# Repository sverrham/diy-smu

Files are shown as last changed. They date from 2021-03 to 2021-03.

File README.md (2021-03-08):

# diy-smu
DIY Source Measurement Unit, four quadrant powersupply and ?.? digit volt/current meter.

This is based on http://www.djerickson.com/diy_smu/index.html but with some changes.

- I plan to use the raspberry pi for control, maybe design a front pannel solution using the compute module.

- I want to miniturize it a bit, change 0805 to 0603 as that is also quite easy to solder by hand.

- I do not have to much experience with the analog part but will let this be project to learn from.

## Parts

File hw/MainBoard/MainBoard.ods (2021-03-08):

Component | Description | Part | References | Value | Footprint | Quantity Per PCB | Datasheet | Manufacturer | partnr | manufacturer
1 | Unpolarized capacitor, small symbol | C_Small | C32 C33 C34 | 15p | C_0603 | 3 | ~ | Samsung Electro-Mechanics | CL10C150JB8NNNC
2 | Unpolarized capacitor, small symbol | C_Small | C43 | 100p | C_0603 | 1 | ~ | Samsung Electro-Mechanics | CL10C101JB8NNNC
3 | Polarized capacitor, small US symbol | CP1_Small | C52 | 150p | C_0603 | 1 | ~ | Samsung Electro-Mechanics | CL10C151JB8NFNC
4 | Unpolarized capacitor, small symbol | C_Small | C44 C45 C46 | 270p | C_0603 | 3 | ~ | Samsung Electro-Mechanics | CL10C271JB8NNNC
5 | Unpolarized capacitor, small symbol | C_Small | C35 | 1000p | C_0603 | 1 | ~ | Samsung Electro-Mechanics | CL10B102KB8NNNC
6 | Polarized capacitor, small US symbol | CP1_Small | C40 C41 C42 C54 C55 | 1000p | C_0603 | 5 | ~ | Samsung Electro-Mechanics | CL10B102KB8NNNC
7 | Unpolarized capacitor, small symbol | C_Small | C10 C11 C12 C13 C14 C15 C16 C17 C19 C21 C22 C23 C24 C25 C26 C27 C28 C29 C30 C31 C39 C47 C51 C53 C56 C58 | .1u | C_0603 | 26 | ~ | Samsung Electro-Mechanics | CL10B104KB8NNNL
8 | Polarized capacitor, small US symbol | CP1_Small | C5 C38 | .1u | C_0603 | 2 | ~ | Samsung Electro-Mechanics | CL10B104KB8NNNL
9 | Unpolarized capacitor, small symbol | C_Small | C4 | .01u 500V | C_0805 | 1 | ~ | WÃ¼rth Elektronik | 885342207014
10 | Unpolarized capacitor, small symbol | C_Small | C37 | 150p 500V | C_0805 | 1 | ~ | Yageo | CC0805JRNPOBBN151
11 | Polarized capacitor, small US symbol | CP1_Small | C50 | 22p 100V | C_0603 | 1 | ~ | KEMET | C0603C220J1GACTU
12 | Unpolarized capacitor, small symbol | C_Small | C36 | 22p 500V DNI | C_0805 | 1 | ~
13 | Polarized capacitor, small US symbol | CP1_Small | C48 C49 | 270p HIV COG 500V | C_0805 | 2 | ~ | KEMET | C0805C271JCGAC7800
14 | Unpolarized capacitor, small symbol | C_Small | C2 C3 C8 C9 C18 C20 C57 | 4.7u 25V | C_0603 | 7 | ~ | Taiyo Yuden | TMK107BBJ475KA-T
15 | Polarized capacitor, small US symbol | CP1_Small | C1 C6 C7 | 47uf 25V | CP_Elec_6.3x7.7 | 3 | ~ | Panasonic | EEE-1EA470WP | Panasonic
16 | DUAL SURFACE MOUNT LOW LEAKAGE DIODE, common cathode, SOT-23 | BAV170 | D6 | BAV170 | SOT-23 | 1 | https://no.mouser.com/datasheet/2/115/ds30234-820460.pdf | Diodes Incorporated | BAV170Q-7-F
17 | DUAL SURFACE MOUNT LOW LEAKAGE DIODE, SOT-23 | BAV199 | D2 D3 D4 D5 | BAV199 | SOT-23 | 4 | https://www.diodes.com/assets/Datasheets/ds30232.pdf | Nexperia | BAV199.215
18 | High-speed switching diodes, dual series, SOT-363 | BAV99S | D1 | BAV99S | SOT-23 | 1 | https://assets.nexperia.com/documents/data-sheet/BAV99_SER.pdf | ON | BAV99LT1
19 | Generic connector, single row, 01x03, script generated (kicad-library-utils/schlib/autogen/connector/) | Conn_01x03_Female | J2 | Conn_01x03_Female | PhoenixContact_MC-G_03x3.81mm_Angled | 1 | ~ | On Shore Technology | OSTOQ033251
20 | Generic connector, single row, 01x06, script generated (kicad-library-utils/schlib/autogen/connector/) | Conn_01x06_Female | J3 | Conn_01x06_Female | PhoenixContact_MC-G_06x3.81mm_Angled | 1 | ~ | On Shore Technology | OSTOQ063251
21 | Generic connector, single row, 01x06, script generated (kicad-library-utils/schlib/autogen/connector/) | Conn_01x06_Female | J4 | Conn_01x06_Female | Molex_KK-6410-06_06x2.54mm_Straight | 1 | ~ | Molex KK | WM2704-NDâ€Ž
22 | Generic connector, single row, 01x14, script generated (kicad-library-utils/schlib/autogen/connector/) | Conn_01x14 | J1 | Conn_01x14 | Multicomp_MC9A12-1434_2x07x2.54mm_Straight | 1 | ~ | On Shore Technology | 302-S141
23 | General purpose signal relay, Kemet EC2 Series, DPDT (2 Form C), non-latching, through hole, 60W/125VA, 220VDC/250VAC, 2A, 5V DC coil | EC2-5NU | K1 K2 | EC2-5NU | Kemet-EC2-5NU-0 | 2 | https://content.kemet.com/datasheets/KEM_R7002_EC2_EE2.pdf | KEMET | EC2-5NU
24 | 100uH CM Choke | DR331-105BE | L1 | DR331-105BE | dr331 | 1 | https://www.bourns.com/pdfs/DR331.pdf | Bourns Inc. | DR331-105BE | Bourns Inc.
25 | 0.2A Ic, 40V Vce, Small Signal NPN Transistor, SOT-23 | MMBT3904 | Q1 Q2 | MMBT3904 | SOT-23 | 2 | https://www.onsemi.com/pub/Collateral/2N3903-D.PDF |  | MMBT3904
26 | Resistor, small US symbol | R_Small_US | R75 R76 R77 R78 R79 R80 R81 R82 R83 R84 R85 R86 | 0 | R_0603 | 12 | ~ | Yageo | AC0603JR-070RL
27 | Resistor, small US symbol | R_Small_US | R14 R45 | 1K | R_0603 | 2 | ~ | Yageo | RT0603FRE071KL
28 | Resistor, small US symbol | R_Small_US | R71 R72 R73 R74 | 1.5K | R_0603 | 4 | ~ | Yageo | RC0603FR-071K5L
29 | Resistor, small US symbol | R_Small_US | R31 R32 R33 R50 R58 | 2K | R_0603 | 5 | ~ | Yageo | RC0603FR-072KL
30 | Resistor, small US symbol | R_Small_US | R11 R17 R51 R54 | 4.99K | R_0603 | 4 | ~ | Yageo | RC0603FR-074K99L
31 | Resistor, small US symbol | R_Small_US | R12 R13 R16 R43 R44 R53 R63 R64 | 10K | R_0603 | 8 | ~ | Yageo | RT0603FRE0710KL
32 | Resistor, small US symbol | R_Small_US | R18 | 15K | R_0603 | 1 | ~ | Yageo | RC0603FR-0715KL
33 | Resistor, small US symbol | R_Small_US | R8 R9 | 20K | R_0603 | 2 | ~ | Yageo | RC0603FR-0720KL
34 | Resistor, small US symbol | R_Small_US | R1 | 100K | R_0603 | 1 | ~ | Yageo | RC0603JR-07100KL
35 | Resistor, small US symbol | R_Small_US | R39 R40 | 100 1W | R_2512 | 2 | ~ | Yageo | RC2512JK-07100RL
36 | Resistor, small US symbol | R_Small_US | R46 R47 R48 R49 | 100K .1% | R_0603 | 4 | ~ | Yageo | RT0603BRD07100KL
37 | Resistor, small US symbol | R_Small_US | R2 R3 R4 R5 R6 R7 R19 R20 R21 R22 R23 R24 R25 R26 R55 R59 R60 R61 R62 R65 R67 R69 R70 | 10K .1% | R_0603 | 23 | ~ | Yageo | RT0603BRD1010KL
38 | Resistor, small US symbol | R_Small_US | R52 | 10K 1206 | R_1206 | 1 | ~ | Yageo | AC1206FR-0710KL
39 | Resistor, small US symbol | R_Small_US | R41 R42 | 2 1W | R_2512 | 2 | ~ | Yageo | RC2512JK-072RL
40 | Resistor, small US symbol | R_Small_US | R29 | 20.5K .1% | R_0603 | 1 | ~ | Yageo | RT0603BRD0720K5L
41 | Resistor, small US symbol | R_Small_US | R15 | 200K 1206 | C_0805 | 1 | ~ | Yageo | RC0805FR-07200KL
42 | Resistor, small US symbol | R_Small_US | R10 | 20K .1% | R_0603 | 1 | ~ | Yageo | RT0603BRD0720KL
43 | Resistor, small US symbol | R_Small_US | R27 R30 R66 R68 | 21.5K .1% | R_0603 | 4 | ~ | Yageo | RT0603BRD0721K5L
44 | Resistor, small US symbol | R_Small_US | R57 | 22.1K .1% | R_0603 | 1 | ~ | Yageo | RT0603BRD0722K1L
45 | Resistor, small US symbol | R_Small_US | R28 | 2K .1% | R_0603 | 1 | ~ | Yageo | RT0603BRE072KL
46 | Resistor, small US symbol | R_Small_US | R56 | 300K .1% 1206 | R_1206 | 1 | ~ | Susumu | RG3216P-3003-B-T1
47 | Resistor, small US symbol | R_Small_US | R37 | 4.99K .1% | R_0603 | 1 | ~ | Yageo | RT0603BRD074K99L
48 | Resistor, small US symbol | R_Small_US | R36 | 49.9K .1% | R_0603 | 1 | ~ | Yageo | RT0603BRD0749K9L
49 | Resistor, small US symbol | R_Small_US | R38 | 499 .25W | R_1206 | 1 | ~ | Yageo | RC1206FR-07499RL
50 | Resistor, small US symbol | R_Small_US | R35 | 560K .1% | R_0603 | 1 | ~ | TE Connectivity Passive Product | CPF0603B560KE1
51 | Resistor, small US symbol | R_Small_US | R34 | 5M 25ppm 1206 | R_1206 | 1 | ~ | Susumu | RG3216P-5004-B-T1
52 | I2C Serial EEPROM, 1Kb, DIP-8/SOIC-8/TSSOP-8/DFN-8 | 24LC01 | U28 | 24LC01 | SOIC-8_3.9x4.9mm_Pitch1.27mm | 1 | http://ww1.microchip.com/downloads/en/DeviceDoc/21711J.pdf | Microchip Technology | 24LC01B/SN
53 | Quad, 16-Bit nanoDAC+ with SPI Interface, TSSOP-16 | AD5686RBRUZ | U9 | AD5686RBRUZ | TSSOP-16_4.4x5mm_Pitch0.65mm | 1 | https://www.analog.com/media/en/technical-documentation/data-sheets/AD5689_5687.pdf | Analog Devices | AD5686RBRUZ
54 | 4.8 kHz Ultralow Noise 24-Bit Sigma-Delta ADC with PGA | AD7190BRUZ | U24 | AD7190BRUZ | TSSOP-24_4.4x7.8mm_Pitch0.65mm | 1 | https://www.analog.com/media/en/technical-documentation/data-sheets/AD7190.pdf | AD7190BRUZ | AD7190BRUZ
55 | Ultralow Noise XFET Voltage References with Current Sink and Source Capability | ADR431ARZ | U8 | ADR431ARZ | SOIC-8_3.9x4.9mm_Pitch1.27mm | 1 | https://www.analog.com/media/en/technical-documentation/data-sheets/adr430_431_433_434_435.pdf | Analog Devices | ADR431BRZ
56 | RF PhotoMOS | AQY22 | U15 U16 | AQY22 | TLP170DF | 2 | https://datasheet.octopart.com/AQY222R1S-Panasonic-datasheet-522434.pdf | Panasonic Electric Works | AQY221R2SZ
57 | Form A, Solid State Relay (Photo MOSFET) 60V, 0.7A, 0.55Ohm, SOP-4 | CPC1002N | U12 | CPC1018N | SOP-4_3.8x4.1mm_Pitch2.54mm | 1 | http://www.ixysic.com/home/pdfs.nsf/www/CPC1002N.pdf/$file/CPC1002N.pdf | IXYS | CPC1018N
58 | Quad SPST Analog Switches, normally OFF, 50Ohm Ron, SOIC-16 | DG444 | U3 U13 U14 | DG444 | SOIC-16_3.9x9.9mm_Pitch1.27mm | 3 | https://www.vishay.com/docs/70054/dg444.pdf | Renesas Electronics America Inc | DG444DYZ
59 | Isolated DC/DC Converters 9-36Vin | DPBW03F | U1 | DPBW03F | DPBW03F15 | 1 | https://www.meanwellusa.com/productPdf.aspx?i=794 | MEAN WELL USA Inc. | DPBW03F-15
60 | I2C Isolator, 2.5 kVrms, Unidirectional Clock, Bidirectional data, SOIC-8 | ISO1541 | U26 | ISO1541 | SOIC-8_3.9x4.9mm_Pitch1.27mm | 1 | http://www.ti.com/lit/ds/symlink/iso1541.pdf | Texas Instruments | ISO1541QDRQ1
61 | Low-Power, Low-Offset Voltage, Dual Comparators, DIP-8/SOIC-8/TO-99-8 | LM393 | U7 | LM393 | SOIC-8_3.9x4.9mm_Pitch1.27mm | 1 | http://www.ti.com/lit/ds/symlink/lm393.pdf | Texas Instruments | LM393ADRG4
62 | 800mA Low-Dropout Linear Regulator, 5.0V fixed output, SOT-223/TO-263 | LT1117-5.0 | U2 | LT1117-5.0 | SOT-223 | 1 | https://www.analog.com/media/en/technical-documentation/data-sheets/1117fd.pdf | ON Semi | NCP1117LPST50T3G
63 | 16-bit I/O expander, I2C, interrupts, w pull-ups, SOIC-28 | MCP23017_SO | U27 | MCP23017_SO | SOIC-28W_7.5x17.9mm_Pitch1.27mm | 1 | http://ww1.microchip.com/downloads/en/DeviceDoc/20001952C.pdf | Microchip Technology | MCP23017T-E/SO
64 | OPAx140High-precision,low-noise,rail-to-railoutput,11-MHzJFET op amp | OPA140 | U19 U20 | OPA140 | SOIC-8_3.9x4.9mm_Pitch1.27mm | 2 | https://www.ti.com/lit/ds/symlink/opa140.pdf?ts=1611999171015 | Texas Instruments | OPA140
65 | OPA2140High-precision,low-noise,rail-to-railoutput,11-MHzJFET op amp | OPA2140 | U4 U5 U6 U10 U17 U22 | OPA2140 | SOIC-8_3.9x4.9mm_Pitch1.27mm | 6 | https://www.ti.com/lit/ds/symlink/opa2140.pdf?ts=1610525555939 | Texas Instruments | OPA2140
66 | Low-Power Quad-Channel Digital Isolator, 150Mbps, 2.5-5.5V, 2.5kV isolation, Fail-Safe Low, SOIC-16 | Si8642BB-B-IS1 | U25 | Si8642BB-B-IS1 | SOIC-16_3.9x9.9mm_Pitch1.27mm | 1 | https://www.silabs.com/documents/public/data-sheets/si864x-datasheet.pdf | Silicon Labs | SI8642BB-B-IS1
67 | Single Low-Noise JFET-Input Operational Amplifiers, DIP-8/SOIC-8 | TL071 | U18 | TL071 | SOIC-8_3.9x4.9mm_Pitch1.27mm | 1 | http://www.ti.com/lit/ds/symlink/tl071.pdf | Texas Instruments | TL071IDR
68 | Dual Low-Noise JFET-Input Operational Amplifiers, DIP-8/SOIC-8 | TL072 | U11 | TL072 | SOIC-8_3.9x4.9mm_Pitch1.27mm | 1 | http://www.ti.com/lit/ds/symlink/tl071.pdf | Texas Instruments | TL072CDRE4
69 | Dual, Low-Noise, 2.18MHz Rail-To-Rail Operational Amplifier | TLC227x | U23 | TLC227x | SOIC-8_3.9x4.9mm_Pitch1.27mm | 1 | https://www.ti.com/lit/ds/symlink/tlc2272a.pdf?ts=1610539637440 | Texas Instruments | TLC2272AIDR
70 | MOSFET Photorelay 1-Form-A, Voff 200V, Ion 200mA, | TLP170D | U21 | TLP170D | TLP170DF | 1 | file:///C:/Users/sverre/AppData/Local/Temp/TLP170D_datasheet_en_20190617.pdf | Toshiba Semiconductor and Storage | TLP170D(F)
71 | Unpolarized capacitor, small symbol | C_Small | e2 | 22p 100V | C_0603 | 1 | ~ | KEMET | C0603C220J1GACTU
72 | Polarized capacitor, small US symbol | CP1_Small | e1 | 4.7uf 25V | CP_Elec_4x5.3 | 1 | ~ | Nichicon | UWX1E4R7MCL1GB | Nichicon
Component Groups: | 72
Component Count: | 189
Fitted Components: | 189
Number of PCBs: | 1
Total components: | 189
Schematic Version: | A
Schematic Date:
PCB Variant: | default
BoM Date: | 07/03/2021 21:25:14
Schematic Source: | MainBoard.sch
KiCad Version: | Eeschema (5.1.9)-1

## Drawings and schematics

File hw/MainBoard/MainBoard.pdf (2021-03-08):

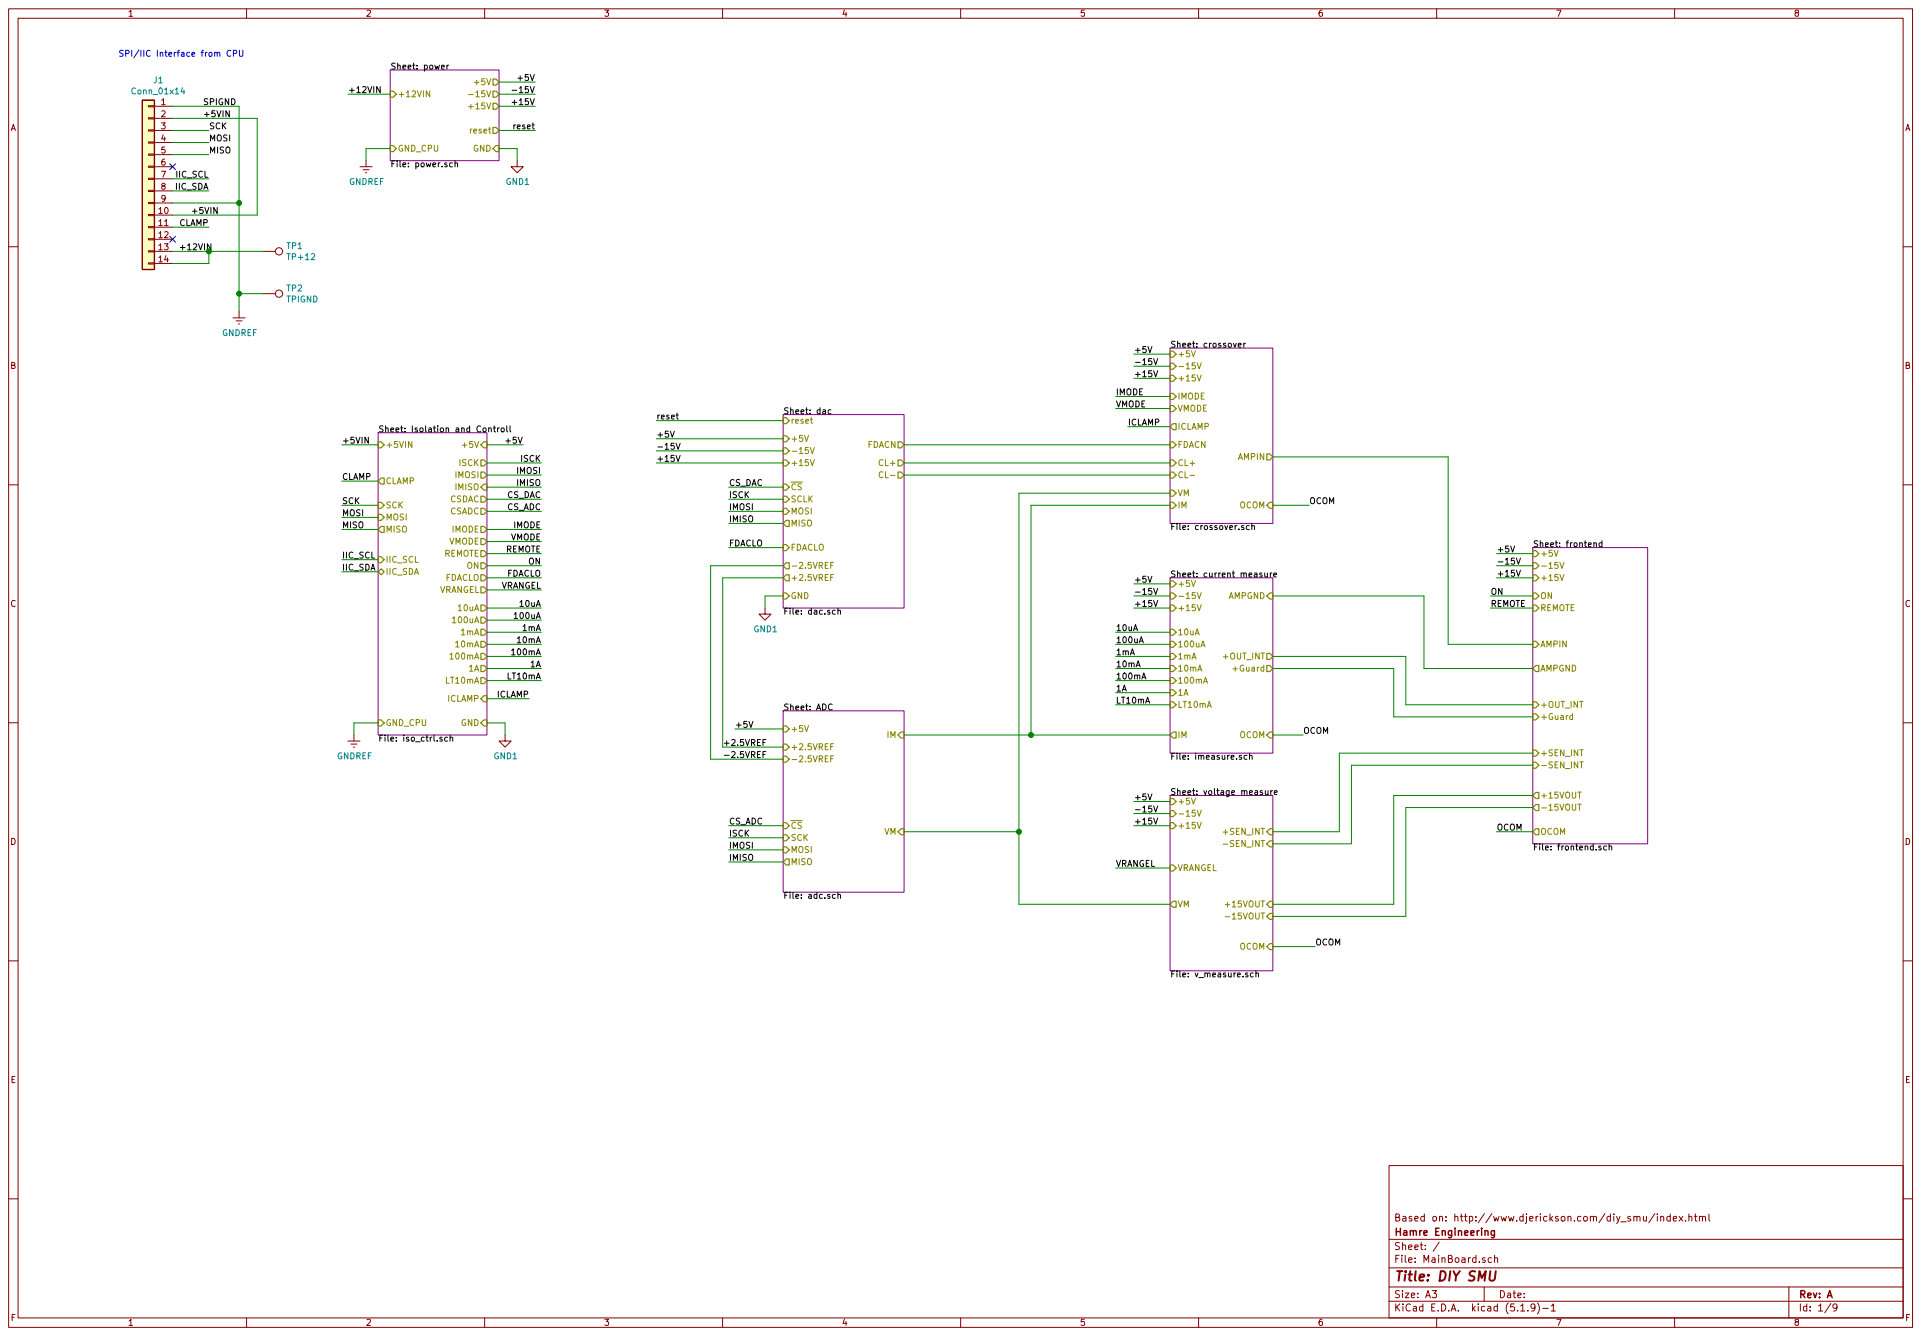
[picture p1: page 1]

SPI/IIC Interface from CPU

Sheet: frontend File: frontend.sch +5V

Based on: http://www.djerickson.com/diy_smu/index.html
File: MainBoard.sch Sheet: / Hamre Engineering

Id: 1/9 Title: DIY SMU

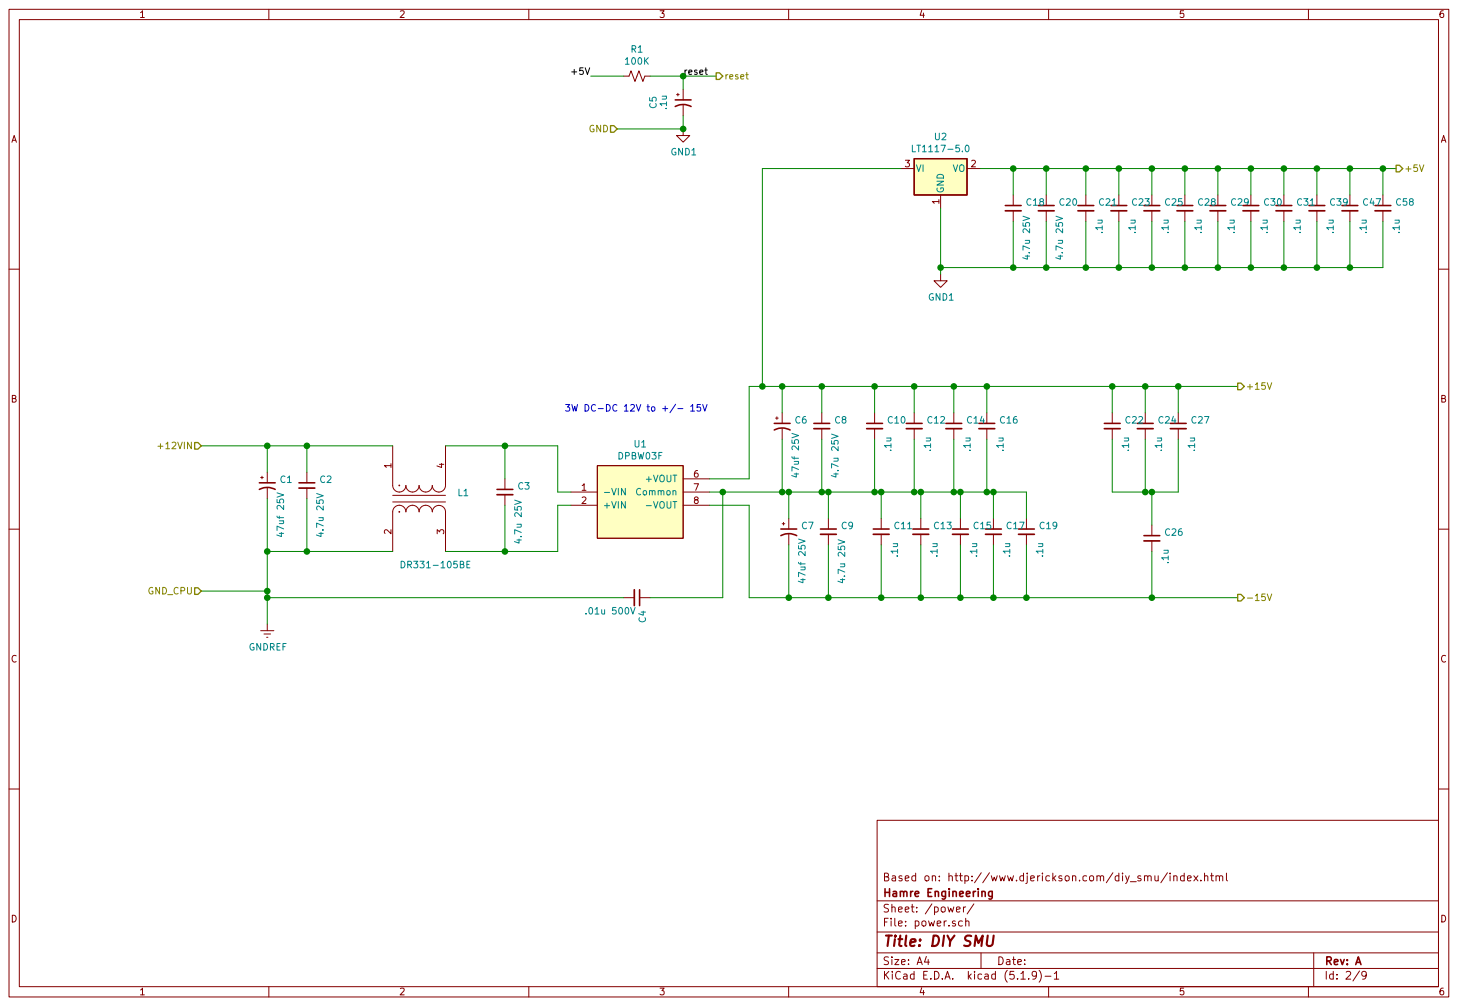
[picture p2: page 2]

Hamre Engineering
Sheet: /power/
File: power.sch
Id: 2/9 Title: DIY SMU

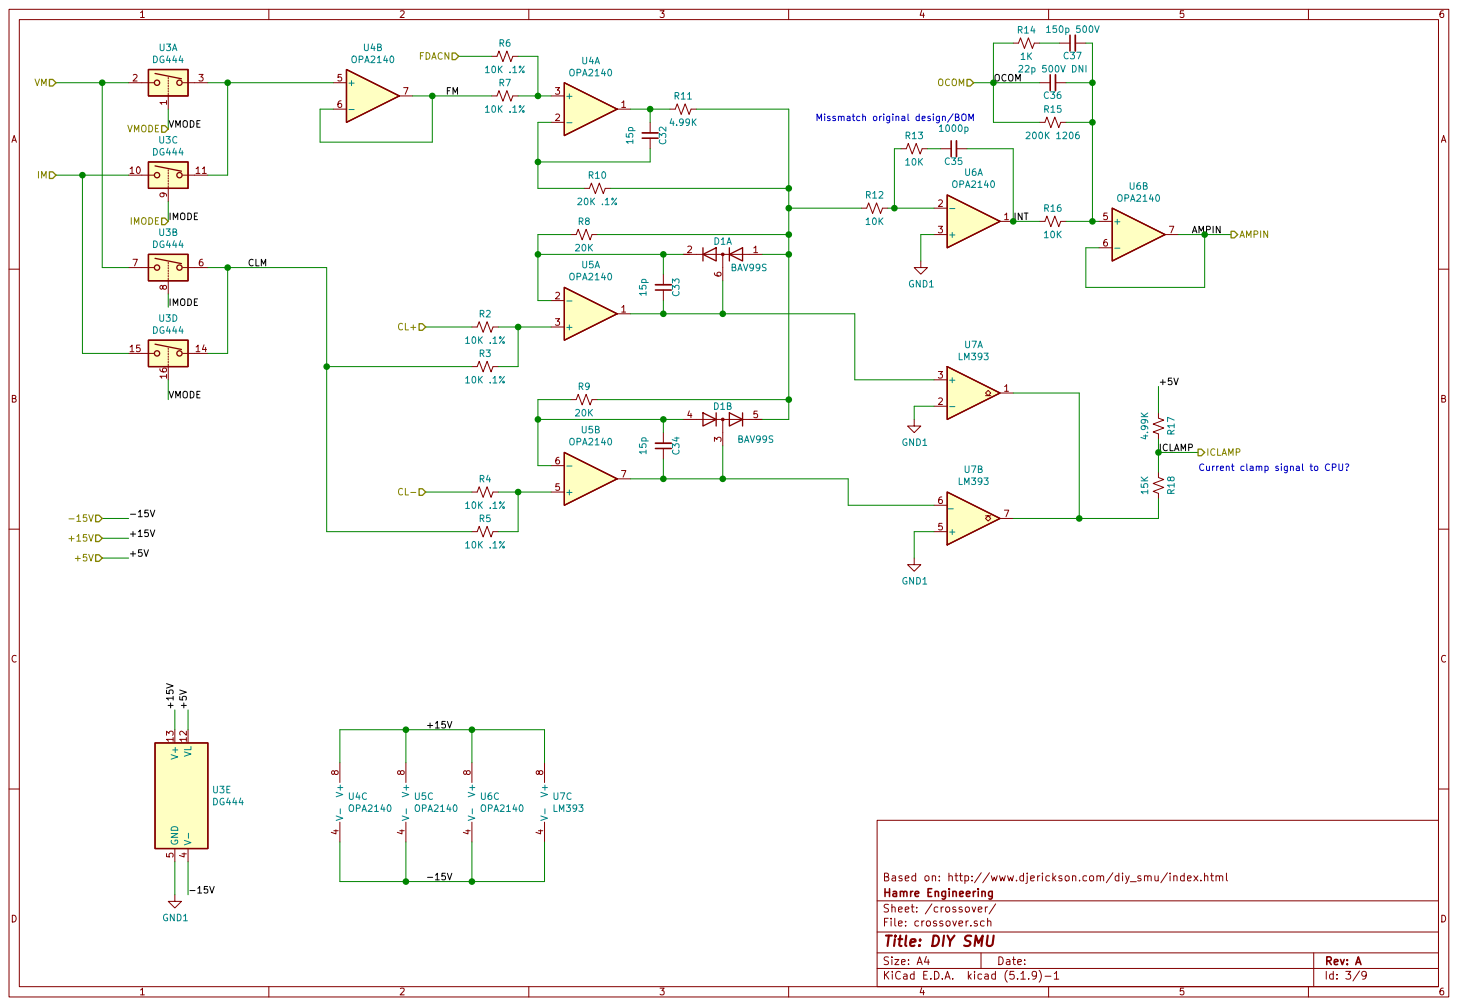
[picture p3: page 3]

Missmatch original design/BOM

Based on: http://www.djerickson.com/diy_smu/index.html
File: crossover.sch Sheet: /crossover/ Hamre Engineering

Id: 3/9 Title: DIY SMU

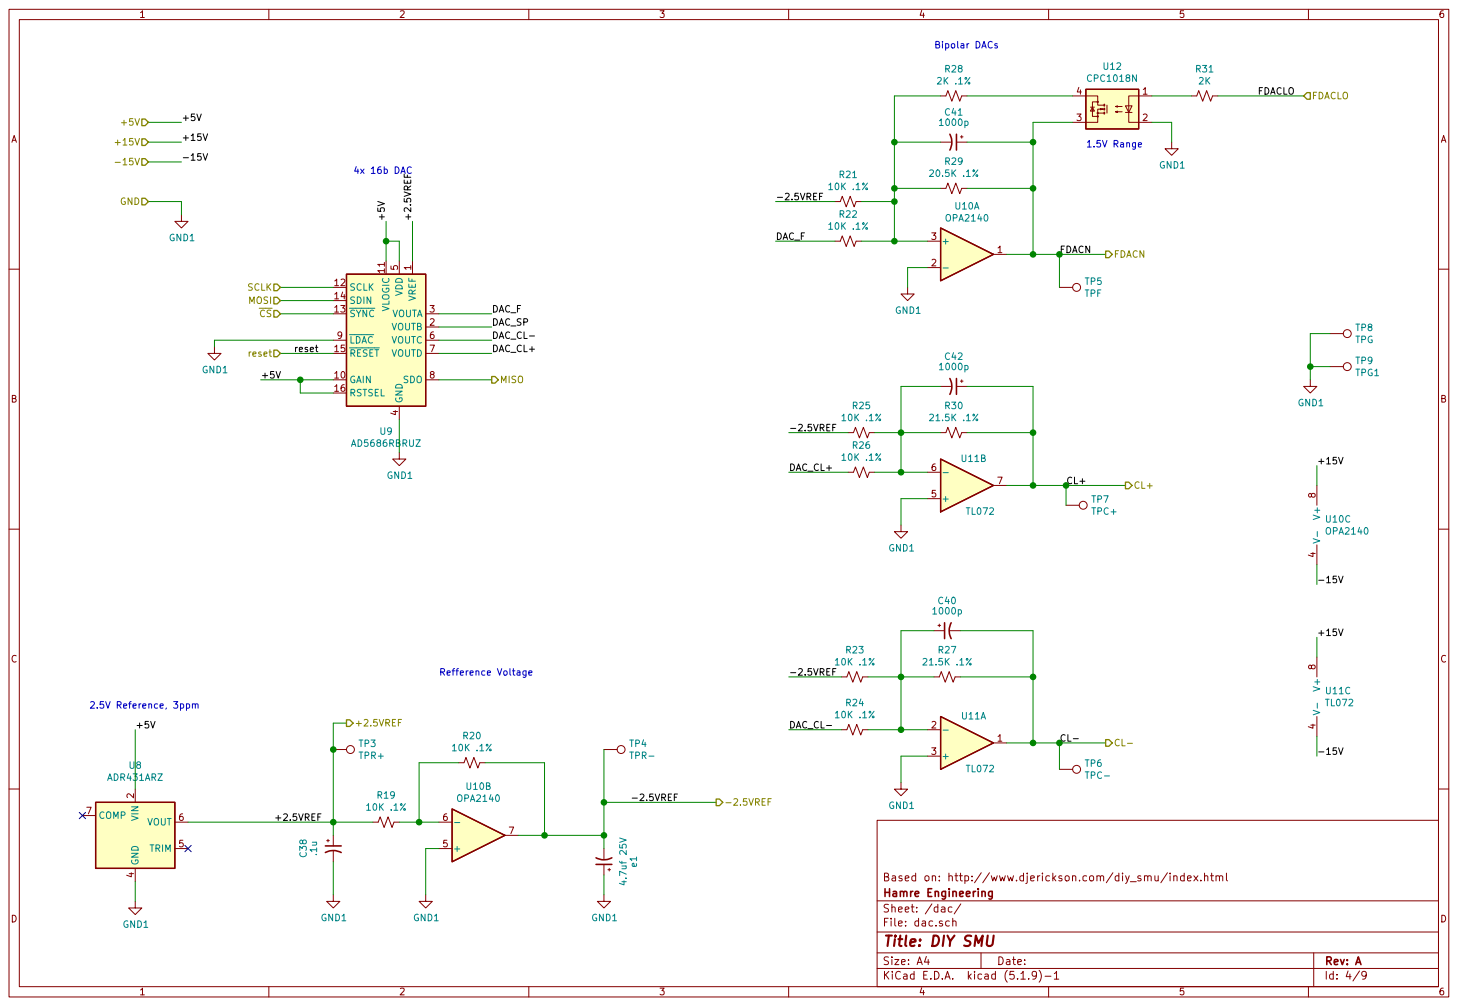
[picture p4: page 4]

File: dac.sch Sheet: /dac/ Hamre Engineering

Id: 4/9 Title: DIY SMU

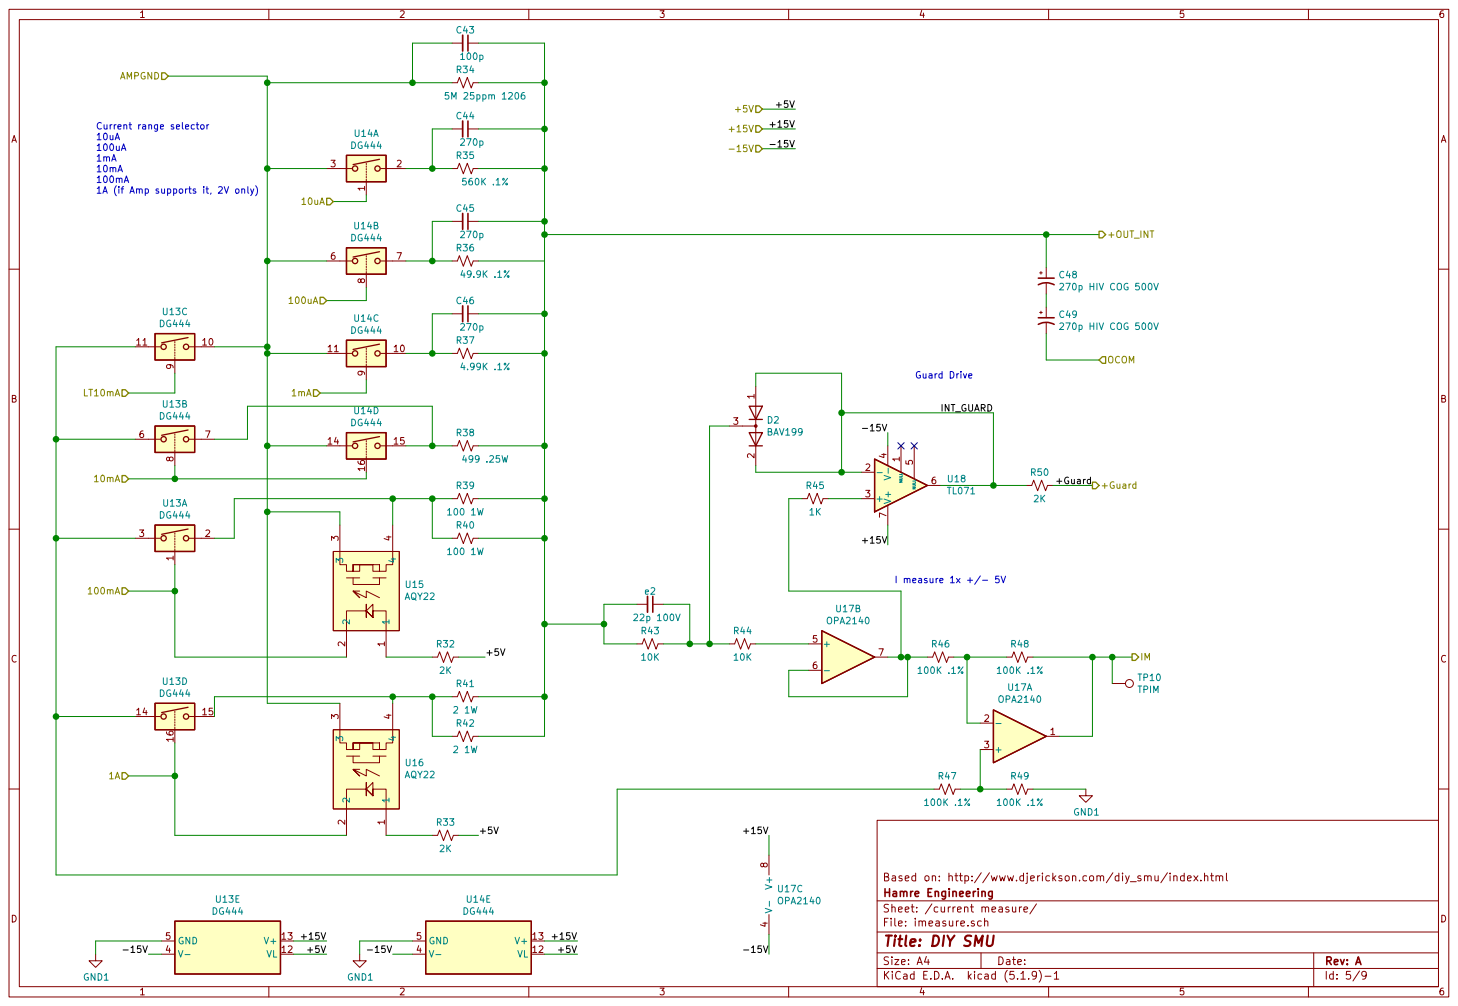
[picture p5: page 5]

I measure 1x +/- 5V Guard Drive Current range selector 10uA

Based on: http://www.djerickson.com/diy_smu/index.html R38

File: imeasure.sch Sheet: /current measure/ Hamre Engineering

Id: 5/9 Title: DIY SMU

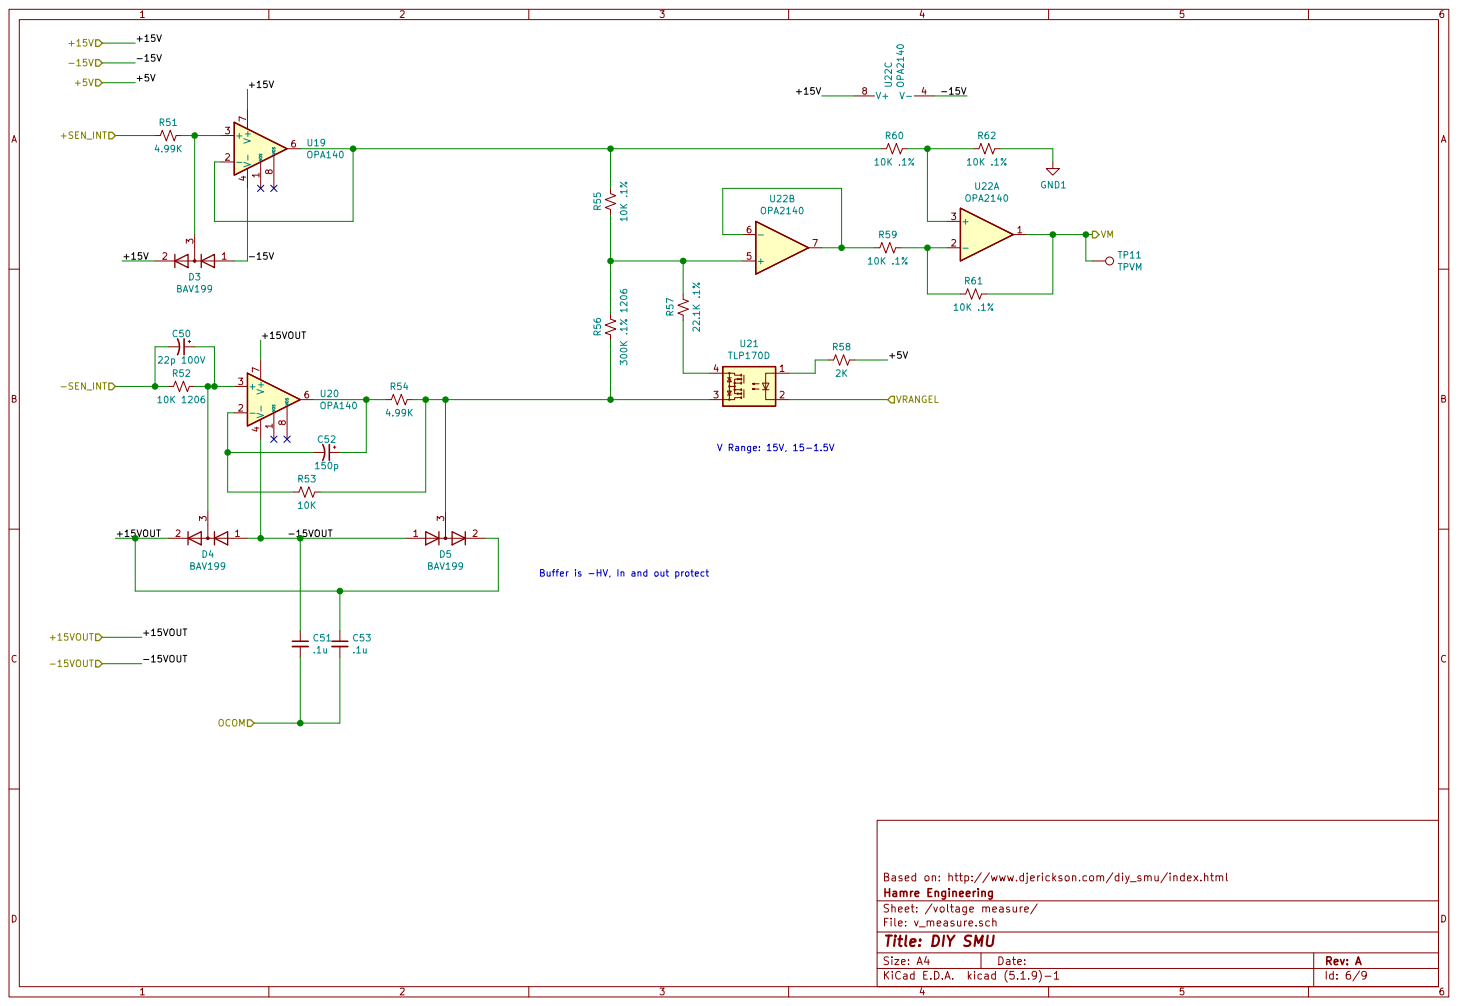
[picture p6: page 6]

Buffer is -HV, In and out protect

Based on: http://www.djerickson.com/diy_smu/index.html
Hamre Engineering
Sheet: /voltage measure/
File: v_measure.sch
Id: 6/9 Title: DIY SMU

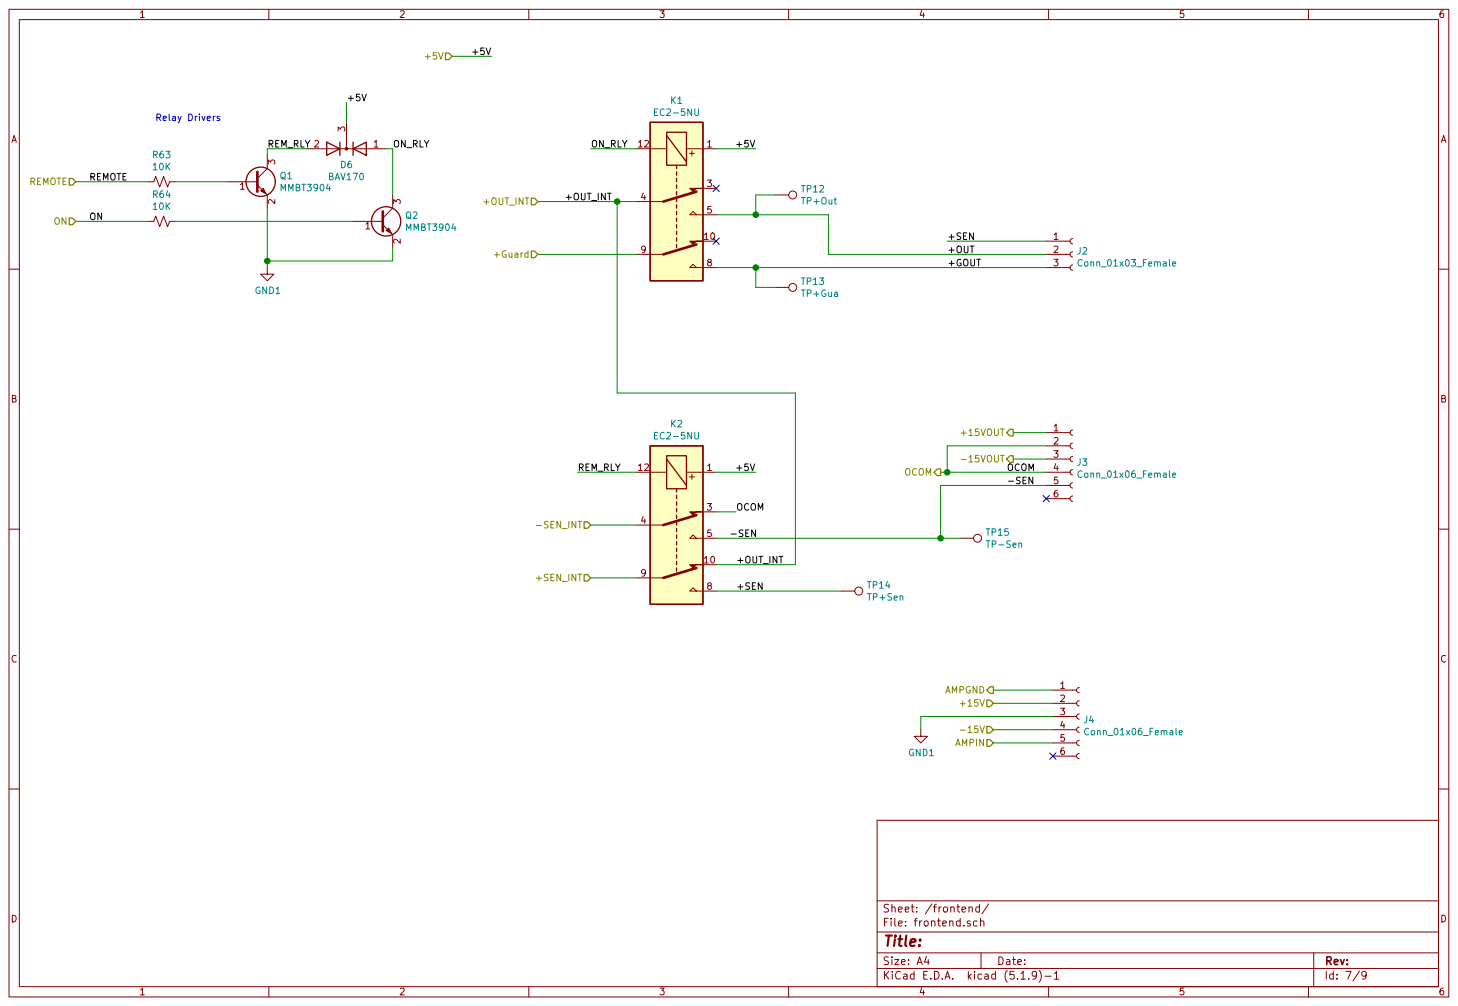
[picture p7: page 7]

2 3 Q2MMBT3904 TP12 TP+Out TP13 GND1 TP+Gua

Id: 7/9 Title: File: frontend.sch Sheet: /frontend/

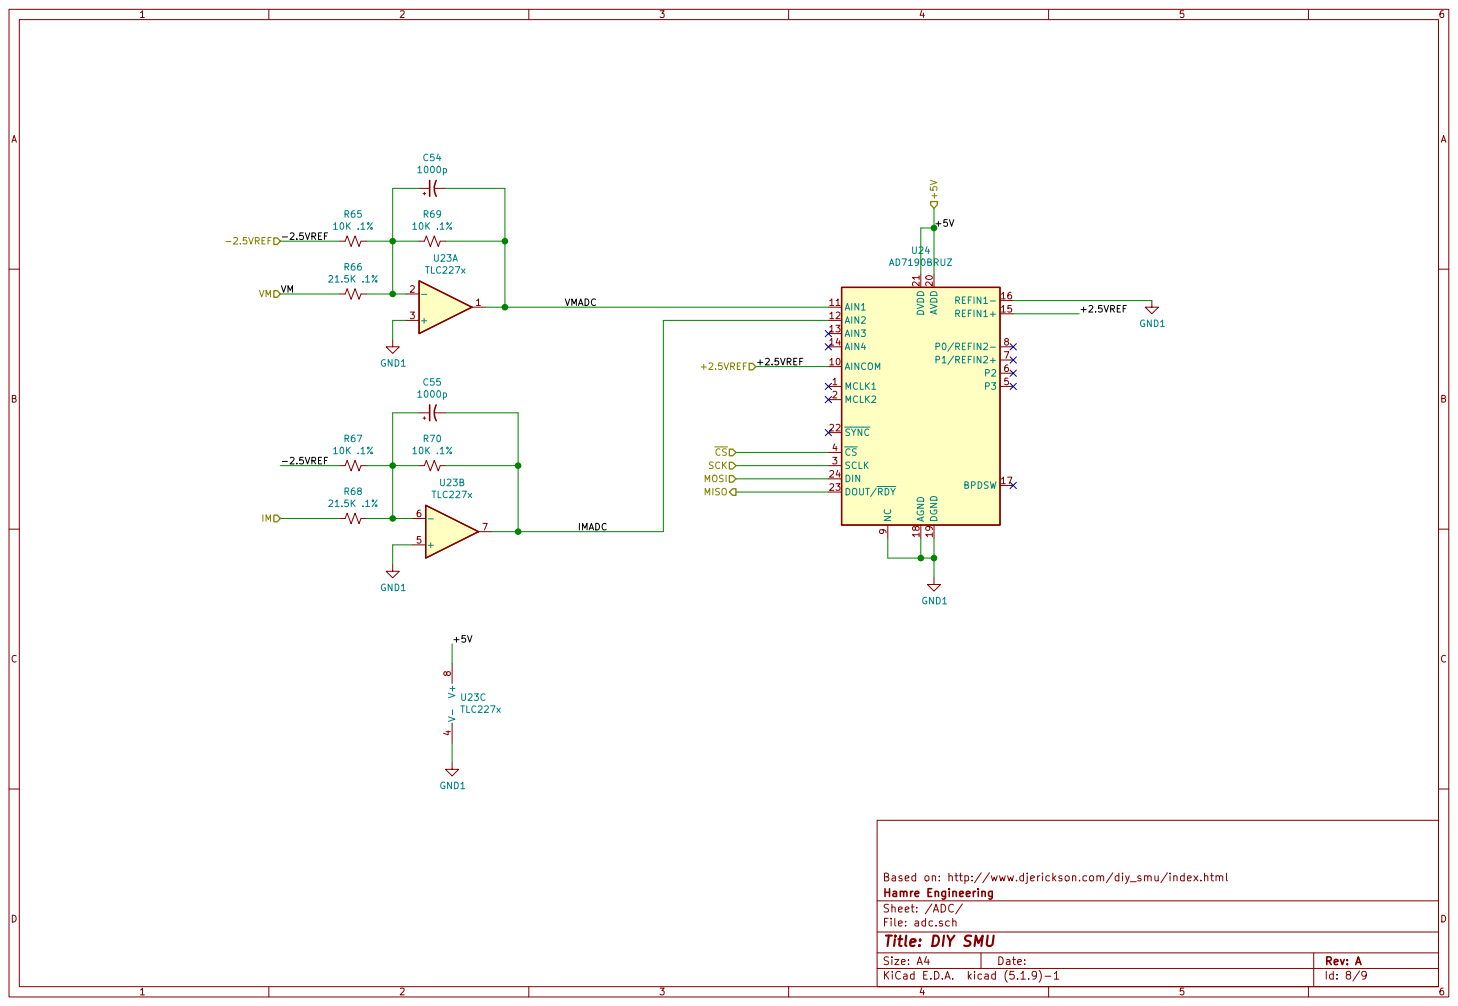
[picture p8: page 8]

Based on: http://www.djerickson.com/diy_smu/index.html
File: adc.sch Sheet: /ADC/ Hamre Engineering

Id: 8/9 Title: DIY SMU

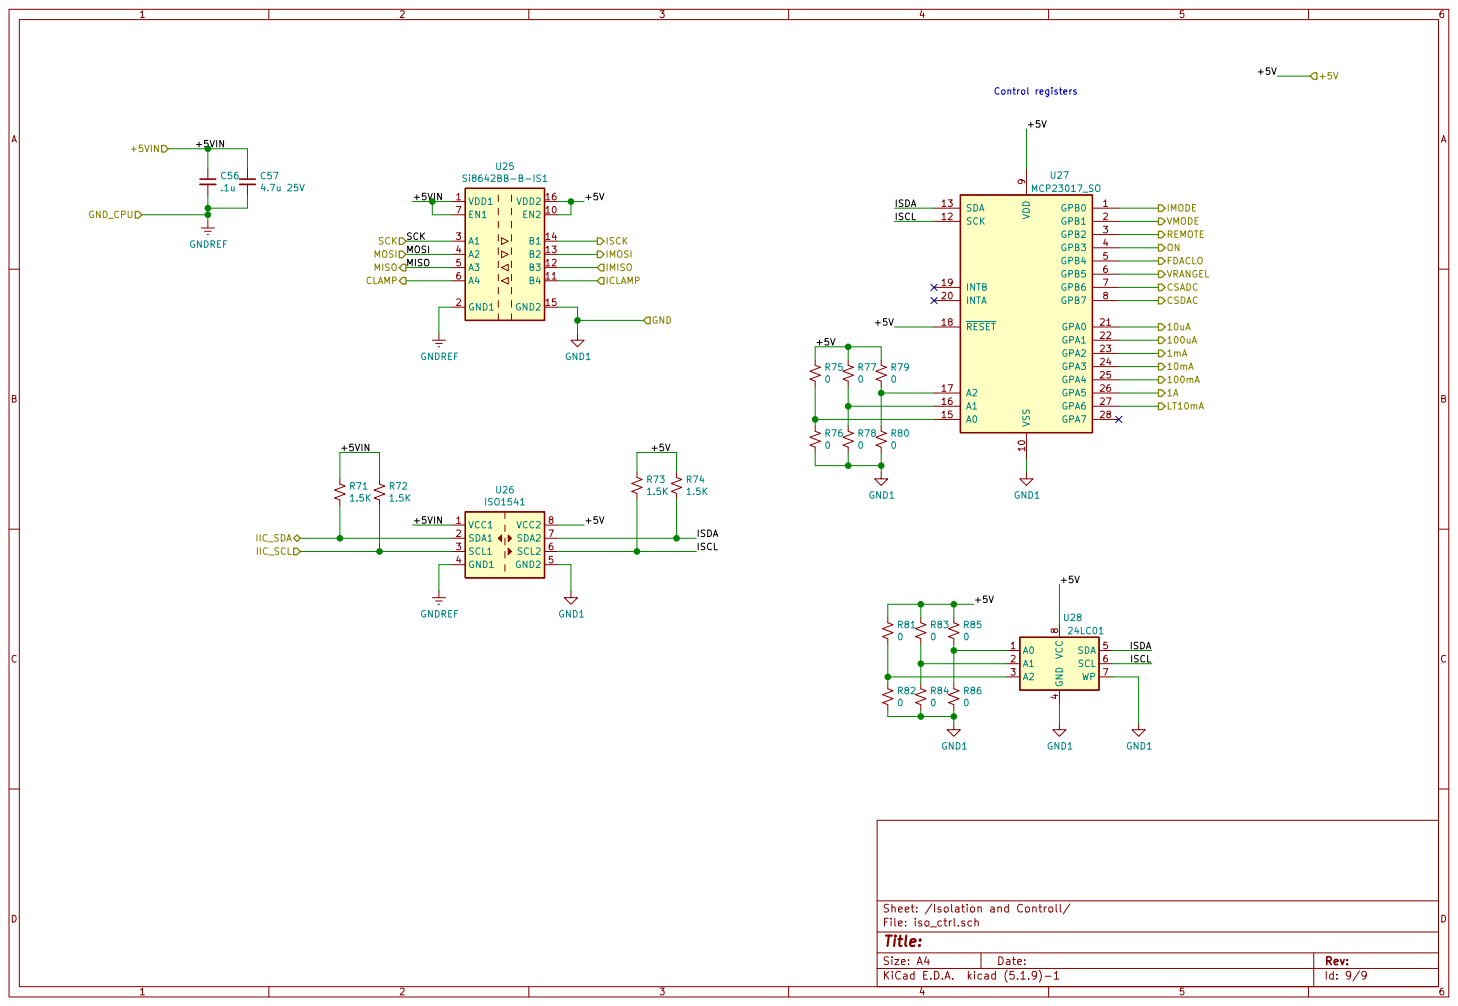
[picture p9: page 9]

4 SDA 5 SCL 6 WP 7 VCC

File: iso_ctrl.sch Sheet: /Isolation and Controll/
Id: 9/9 Title:

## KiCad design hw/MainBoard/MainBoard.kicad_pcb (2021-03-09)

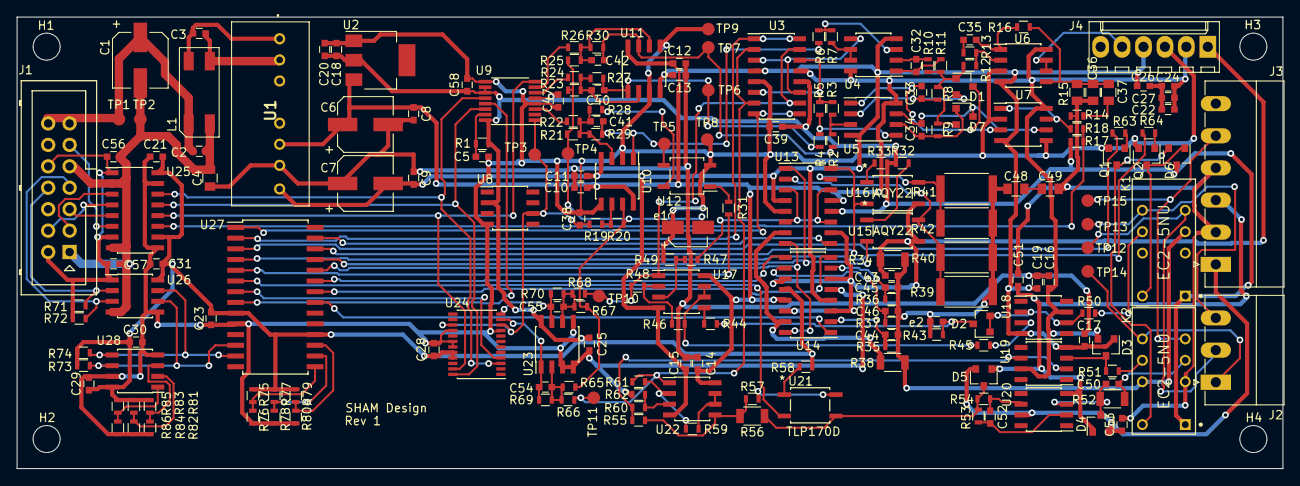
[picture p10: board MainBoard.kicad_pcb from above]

Board: 2 copper layers, 150.0 x 53.5 mm, 209 parts (0 on the bottom side), 130 nets.

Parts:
C1, C6, C7: 47uf 25V; CP_Elec_6.3x7.7
C2, C3, C8, C9, C18, C20, C57: 4.7u 25V; C_0603
C4: .01u 500V; C_0805
C5, C10, C11, C12, C13, C14, C15, C16, C17, C19, C21, C22, C23, C24, C25, C26, C27, C28, C29, C30, C31, C38, C39, C47, C51, C53, C56, C58: .1u; C_0603
C32, C33, C34: 15p; C_0603
C35, C40, C41, C42, C54, C55: 1000p; C_0603
C36: 22p 500V DNI; C_0805
C37: 150p 500V; C_0805
C43: 100p; C_0603
C44, C45, C46: 270p; C_0603
C48, C49: 270p HIV COG 500V; C_0805
C50: 22p 100V; C_0603
C52: 150p; C_0603
D1: BAV99LT1; SOT-23
D2, D3, D4, D5: BAV199; SOT-23
D6: BAV170; SOT-23
D7: BAV199LT1; SOT-23
H1, H2, H3, H4: MountingHole; MountingHole_3.2mm_M3
J1: Conn_01x14; Multicomp_MC9A12-1434_2x07x2.54mm_Straight
J2: Conn_01x03_Female; PhoenixContact_MC-G_03x3.81mm_Angled
J3: Conn_01x06_Female; PhoenixContact_MC-G_06x3.81mm_Angled
J4: Conn_01x06_Female; Molex_KK-6410-06_06x2.54mm_Straight
K1, K2: EC2-5NU; Kemet-EC2-5NU-0
L1: DR331-105BE; dr331
Q1, Q2: MMBT3904; SOT-23
R1: 100K; R_0603
R2, R3, R4, R5, R6, R7, R19, R20, R21, R22, R23, R24, R25, R26, R55, R59, R60, R61, R62, R65, R67, R69, R70: 10K .1%; R_0603
R8, R9: 20K; R_0603
R10: 20K .1%; R_0603
R11, R17, R51, R54: 4.99K; R_0603
R12, R13, R16, R43, R44, R53, R63, R64: 10K; R_0603
R14, R45: 1K; R_0603
R15: 200K 1206; C_0805
R18: 15K; R_0603
R27, R30, R66, R68: 21.5K .1%; R_0603
R28: 2K .1%; R_0603
R29: 20.5K .1%; R_0603
R31, R32, R33, R50, R58: 2K; R_0603
R34: 5M 25ppm 1206; R_1206
R35: 560K .1%; R_0603
R36: 49.9K .1%; R_0603
R37: 4.99K .1%; R_0603
R38: 499 .25W; R_1206
R39, R40: 100 1W; R_2512
R41, R42: 2 1W; R_2512
R46, R47, R48, R49: 100K .1%; R_0603
R52: 10K 1206; R_1206
R56: 300K .1% 1206; R_1206
R57: 22.1K .1%; R_0603
R71, R72, R73, R74: 1.5K; R_0603
R75, R76, R77, R78, R79, R80, R81, R82, R83, R84, R85, R86: 0; R_0603
TP1: TP+12; Measurement_Point_Round-SMD-Pad_Small
TP2: TPIGND; Measurement_Point_Round-SMD-Pad_Small
TP3: TPR+; Measurement_Point_Round-SMD-Pad_Small
TP4: TPR-; Measurement_Point_Round-SMD-Pad_Small
TP5: TPF; Measurement_Point_Round-SMD-Pad_Small
TP6: TPC-; Measurement_Point_Round-SMD-Pad_Small
TP7: TPC+; Measurement_Point_Round-SMD-Pad_Small
TP8: TPG; Measurement_Point_Round-SMD-Pad_Small
TP9: TPG1; Measurement_Point_Round-SMD-Pad_Small
TP10: TPIM; Measurement_Point_Round-SMD-Pad_Small
TP11: TPVM; Measurement_Point_Round-SMD-Pad_Small
TP12: TP+Out; Measurement_Point_Round-SMD-Pad_Small
TP13: TP+Gua; Measurement_Point_Round-SMD-Pad_Small
TP14: TP+Sen; Measurement_Point_Round-SMD-Pad_Small
TP15: TP-Sen; Measurement_Point_Round-SMD-Pad_Small
U1: DPBW03F; DPBW03F15
U2: LT1117-5.0; SOT-223
U3, U13, U14: DG444; SOIC-16_3.9x9.9mm_Pitch1.27mm
U4, U5, U6, U10, U17, U22: OPA2140; SOIC-8_3.9x4.9mm_Pitch1.27mm
U7: LM393; SOIC-8_3.9x4.9mm_Pitch1.27mm
U8: ADR431ARZ; SOIC-8_3.9x4.9mm_Pitch1.27mm
U9: AD5686RBRUZ; TSSOP-16_4.4x5mm_Pitch0.65mm
U11: TL072; SOIC-8_3.9x4.9mm_Pitch1.27mm
U12: CPC1018N; SOP-4_3.8x4.1mm_Pitch2.54mm
U15, U16: AQY22; TLP170DF
U18: TL071; SOIC-8_3.9x4.9mm_Pitch1.27mm
U19, U20: OPA140; SOIC-8_3.9x4.9mm_Pitch1.27mm
U21: TLP170D; TLP170DF
U23: TLC227x; SOIC-8_3.9x4.9mm_Pitch1.27mm
U24: AD7190BRUZ; TSSOP-24_4.4x7.8mm_Pitch0.65mm
U25: Si8642BB-B-IS1; SOIC-16_3.9x9.9mm_Pitch1.27mm
U26: ISO1541; SOIC-8_3.9x4.9mm_Pitch1.27mm
U27: MCP23017_SO; SOIC-28W_7.5x17.9mm_Pitch1.27mm
U28: 24LC01; SOIC-8_3.9x4.9mm_Pitch1.27mm
e1: 4.7uf 25V; CP_Elec_4x5.3
e2: 22p 100V; C_0603

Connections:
/1A: U13.16, U16.2, U27.26
/1mA: U14.9, U27.23
/10mA: U13.8, U14.16, U27.24
/10uA: U14.1, U27.21
/100mA: U13.1, U15.2, U27.25
/100uA: U14.8, U27.22
/+2.5VREF: C38.1, R19.2, TP3.1, U8.6, U9.1, U24.10, U24.15
/+5V: C18.1, C20.1, C21.1, C23.1, C25.1, C28.1, C29.1, C30.1, C31.1, C39.1, C47.1, C58.1, D6.3, K1.1, K2.1, R1.2, R17.2, R32.1, R33.1, R58.1, R73.1, R74.1, R75.1, R77.1, R79.1, R81.1, R83.1, R85.1, U2.2, U3.12, U8.2, U9.5, U9.10, U9.11, U9.16, U13.12, U14.12, U23.8, U24.20, U24.21, U25.10, U25.16, U26.8, U27.9, U27.18, U28.8
/+5VIN: C56.1, C57.1, J1.2, J1.10, R71.1, R72.1, U25.1, U25.7, U26.1
/+12VIN: C1.1, C2.1, J1.13, J1.14, L1.1, TP1.1
/+15V: C6.1, C8.1, C10.1, C12.1, C14.1, C16.1, C22.1, C24.1, C27.1, D3.2, J4.2, U1.6, U2.3, U3.13, U4.8, U5.8, U6.8, U7.8, U10.8, U11.8, U13.13, U14.13, U17.8, U18.7, U19.7, U22.8
/-2.5VREF: R20.1, R21.2, R23.2, R25.2, R65.2, R67.2, TP4.1, U10.7, e1.2
/-15V: C7.2, C9.2, C11.2, C13.2, C15.2, C17.2, C19.2, C26.2, D3.1, J4.4, U1.8, U3.4, U4.4, U5.4, U6.4, U7.4, U10.4, U11.4, U13.4, U14.4, U17.4, U18.4, U19.4, U22.4
/ADC/IM: R48.1, R68.2, TP10.1, U3.10, U3.15, U17.1
/ADC/IMADC: C55.2, R70.1, U23.7, U24.12
/ADC/VM: R61.1, R66.2, TP11.1, U3.2, U3.7, U22.1
/ADC/VMADC: C54.2, R69.1, U23.1, U24.11
/CLAMP: J1.11, U25.6
/CS_ADC: U24.4, U27.7
/CS_DAC: U9.13, U27.8
/FDACLO: R31.1, U27.5
/ICLAMP: R17.1, R18.2, U25.11
/IIC_SCL: J1.7, R72.2, U26.3
/IIC_SDA: J1.8, R71.2, U26.2
/IMISO: U9.8, U24.23, U25.12
/IMODE: U3.8, U3.9, U27.1
/IMOSI: U9.14, U24.24, U25.13
/ISCK: U9.12, U24.3, U25.14
/Isolation and Controll/ISCL: R73.2, U26.6, U27.12, U28.6
/Isolation and Controll/ISDA: R74.2, U26.7, U27.13, U28.5
/LT10mA: U13.9, U27.27
/MISO: J1.5, U25.5
/MOSI: J1.4, U25.4
/OCOM: C36.1, C49.2, C51.2, C53.2, J3.2, J3.4, K2.3, R14.2, R15.2
/ON: R64.2, U27.4
/REMOTE: R63.2, U27.3
/SCK: J1.3, U25.3
/VMODE: U3.1, U3.16, U27.2
/VRANGEL: U21.2, U27.6
/crossover/AMPIN: J4.5, U6.6, U6.7
/crossover/CL+: C42.1, R2.2, R30.1, TP7.1, U11.7
/crossover/CL-: C40.2, R4.2, R27.1, TP6.1, U11.1
/crossover/CLM: R3.2, R5.2, U3.6, U3.14
/crossover/FDACN: C41.1, R6.2, R29.1, TP5.1, U10.1, U12.3
/crossover/FM: R7.2, U4.6, U4.7
/crossover/INT: C35.2, R16.2, U6.1
/current measure/+Guard: K1.9, R50.1
/current measure/+OUT_INT: C43.1, C44.1, C45.1, C46.1, C48.1, K1.4, K2.10, R34.1, R35.1, R36.1, R37.1, R38.1, R39.1, R40.1, R41.1, R42.1, R43.2, e2.2
/current measure/AMPGND: C43.2, J4.1, R34.2, U13.10, U14.3, U14.6, U14.11, U14.14, U15.3, U16.3
/current measure/INT_GUARD: D2.1, D2.2, R50.2, U18.2, U18.6
/dac/DAC_CL+: R26.2, U9.7
/dac/DAC_CL-: R24.2, U9.6
/dac/DAC_F: R22.2, U9.3
/frontend/+15VOUT: C53.1, D4.2, D5.2, J3.1, U20.7
/frontend/+GOUT: J2.3, K1.8, TP13.1
/frontend/+OUT: J2.2, K1.5, TP12.1
/frontend/+SEN: J2.1, K2.8, TP14.1
/frontend/+SEN_INT: K2.9, R51.2
/frontend/-15VOUT: C51.1, D4.1, D5.1, J3.3, U20.4
/frontend/-SEN: J3.5, K2.5, TP15.1
/frontend/-SEN_INT: C50.2, K2.4, R52.2
/frontend/ON_RLY: D6.1, K1.12, Q2.3
/frontend/REM_RLY: D6.2, K2.12, Q1.3
/reset: C5.1, R1.1, U9.15
GND1: C5.2, C18.2, C20.2, C21.2, C23.2, C25.2, C28.2, C29.2, C30.2, C31.2, C38.2, C39.2, C47.2, C58.2, J4.3, Q1.2, Q2.2, R49.1, R62.1, R76.2, R78.2, R80.2, R82.2, R84.2, R86.2, TP8.1, TP9.1, U2.1, U3.5, U6.3, U7.2, U7.5, U8.4, U9.4, U9.9, U10.2, U10.5, U11.3, U11.5, U12.2, U13.5, U14.5, U23.3, U23.4, U23.5, U24.9, U24.16, U24.18, U24.19, U25.9, U25.15, U26.5, U27.10, U28.4, U28.7, e1.1
GNDREF: C1.2, C2.2, C4.2, C56.2, C57.2, J1.1, J1.9, L1.2, TP2.1, U25.2, U25.8, U26.4
unnamed: C3.1, L1.4, U1.1
unnamed: C3.2, L1.3, U1.2
unnamed: C4.1, C6.2, C7.1, C8.2, C9.1, C10.2, C11.1, C12.2, C13.1, C14.2, C15.1, C16.2, C17.1, C19.1, U1.7
unnamed: C22.2, C24.2, C26.1, C27.2
unnamed: C32.1, R10.2, U4.2
unnamed: C32.2, R11.2, U4.1
unnamed: C33.1, D1.3, U5.1, U7.3
unnamed: C33.2, D1.2, R8.2, U5.2
unnamed: C34.1, D7.3, U5.7, U7.6
unnamed: C34.2, D7.1, R9.2, U5.6
unnamed: C35.1, R13.1
unnamed: C36.2, C37.2, R15.1, R16.1, U6.5
unnamed: C37.1, R14.1
unnamed: C40.1, R23.1, R24.1, R27.2, U11.2
unnamed: C41.2, R21.1, R22.1, R28.2, R29.2, U10.3
unnamed: C42.2, R25.1, R26.1, R30.2, U11.6
unnamed: C44.2, R35.2, U14.2
unnamed: C45.2, R36.2, U14.7
unnamed: C46.2, R37.2, U14.10
unnamed: C48.2, C49.1
unnamed: C50.1, D4.3, R52.1, U20.3
unnamed: C52.1, R54.2, U20.6
unnamed: C52.2, R53.2, U20.2
unnamed: C54.1, R65.1, R66.1, R69.2, U23.2
unnamed: C55.1, R67.1, R68.1, R70.2, U23.6
unnamed: D1.1, D7.2, R8.1, R9.1, R10.1, R11.1, R12.2
unnamed: D2.3, R43.1, R44.2, e2.1
unnamed: D3.3, R51.1, U19.3
unnamed: D5.3, R53.1, R54.1, R56.2, U21.3
unnamed: Q1.1, R63.1
unnamed: Q2.1, R64.1
unnamed: R2.1, R3.1, U5.3
unnamed: R4.1, R5.1, U5.5
unnamed: R6.1, R7.1, U4.3
unnamed: R12.1, R13.2, U6.2
unnamed: R18.1, U7.1, U7.7
unnamed: R19.1, R20.2, U10.6
unnamed: R28.1, U12.4
unnamed: R31.2, U12.1
unnamed: R32.2, U15.1
unnamed: R33.2, U16.1
unnamed: R38.2, U13.7, U14.15
unnamed: R39.2, R40.2, U13.2, U15.4
unnamed: R41.2, R42.2, U13.15, U16.4
unnamed: R44.1, U17.5
unnamed: R45.1, U18.3
unnamed: R45.2, R46.2, U17.6, U17.7
unnamed: R46.1, R48.2, U17.2
unnamed: R47.1, R49.2, U17.3
unnamed: R47.2, U13.3, U13.6, U13.11, U13.14
unnamed: R55.1, R60.2, U19.2, U19.6
unnamed: R55.2, R56.1, R57.1, U22.5
unnamed: R57.2, U21.4
unnamed: R58.2, U21.1
unnamed: R59.1, R61.2, U22.2
unnamed: R59.2, U22.6, U22.7
unnamed: R60.1, R62.2, U22.3
unnamed: R75.2, R76.1, U27.15
unnamed: R77.2, R78.1, U27.16
unnamed: R79.2, R80.1, U27.17
unnamed: R81.2, R82.1, U28.3
unnamed: R83.2, R84.1, U28.2
unnamed: R85.2, R86.1, U28.1
unnamed: U3.3, U3.11, U4.5

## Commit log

2021-03-08 Initial commit with main board
    [MainBoard.kicad_pcb, MainBoard.ods, MainBoard.sch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]
2021-03-08 Add footprints uesd
2021-03-09 Fix issues with footprints, missing solder mask
2021-03-09 Update schema, fix wrong package for BAV99 D1, add mounting holes to schema.
    [MainBoard.sch, crossover.sch]
2021-03-09 Updated layout with updated schema
    [MainBoard.kicad_pcb]

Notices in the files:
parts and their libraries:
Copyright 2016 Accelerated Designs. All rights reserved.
